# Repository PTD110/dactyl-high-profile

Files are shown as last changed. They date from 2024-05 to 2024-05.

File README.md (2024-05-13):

# Yet another Dactyl Manuform Spinoff (Low Profile)



This repo is a _fork of a_ re-implementation of the [Dactyl Manuform Tight](https://github.com/okke-formsma/dactyl-manuform-tight) in python, with a few of my own changes.

There are some hacks in here to get the border walls and thumb cluster to line up properly at the current tenting angle and key layout.
I didn't build this script with the goal of making it easy to share and extend... so if you're using this repo as a starting point for your own dactyl build, good luck, and beware of some shard edges.

## Generating OpenSCAD Models

This script is tested against Python 3.8.0

Intall dependencies with `pip install -r requirements.txt`

Run a one-off scad model build with `make run`

Watch and rebuild scad models with `make watch` (useful for development)

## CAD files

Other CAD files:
things/left.scad
things/left_bottom_plate.scad
things/right.scad
things/right_bottom_plate.scad

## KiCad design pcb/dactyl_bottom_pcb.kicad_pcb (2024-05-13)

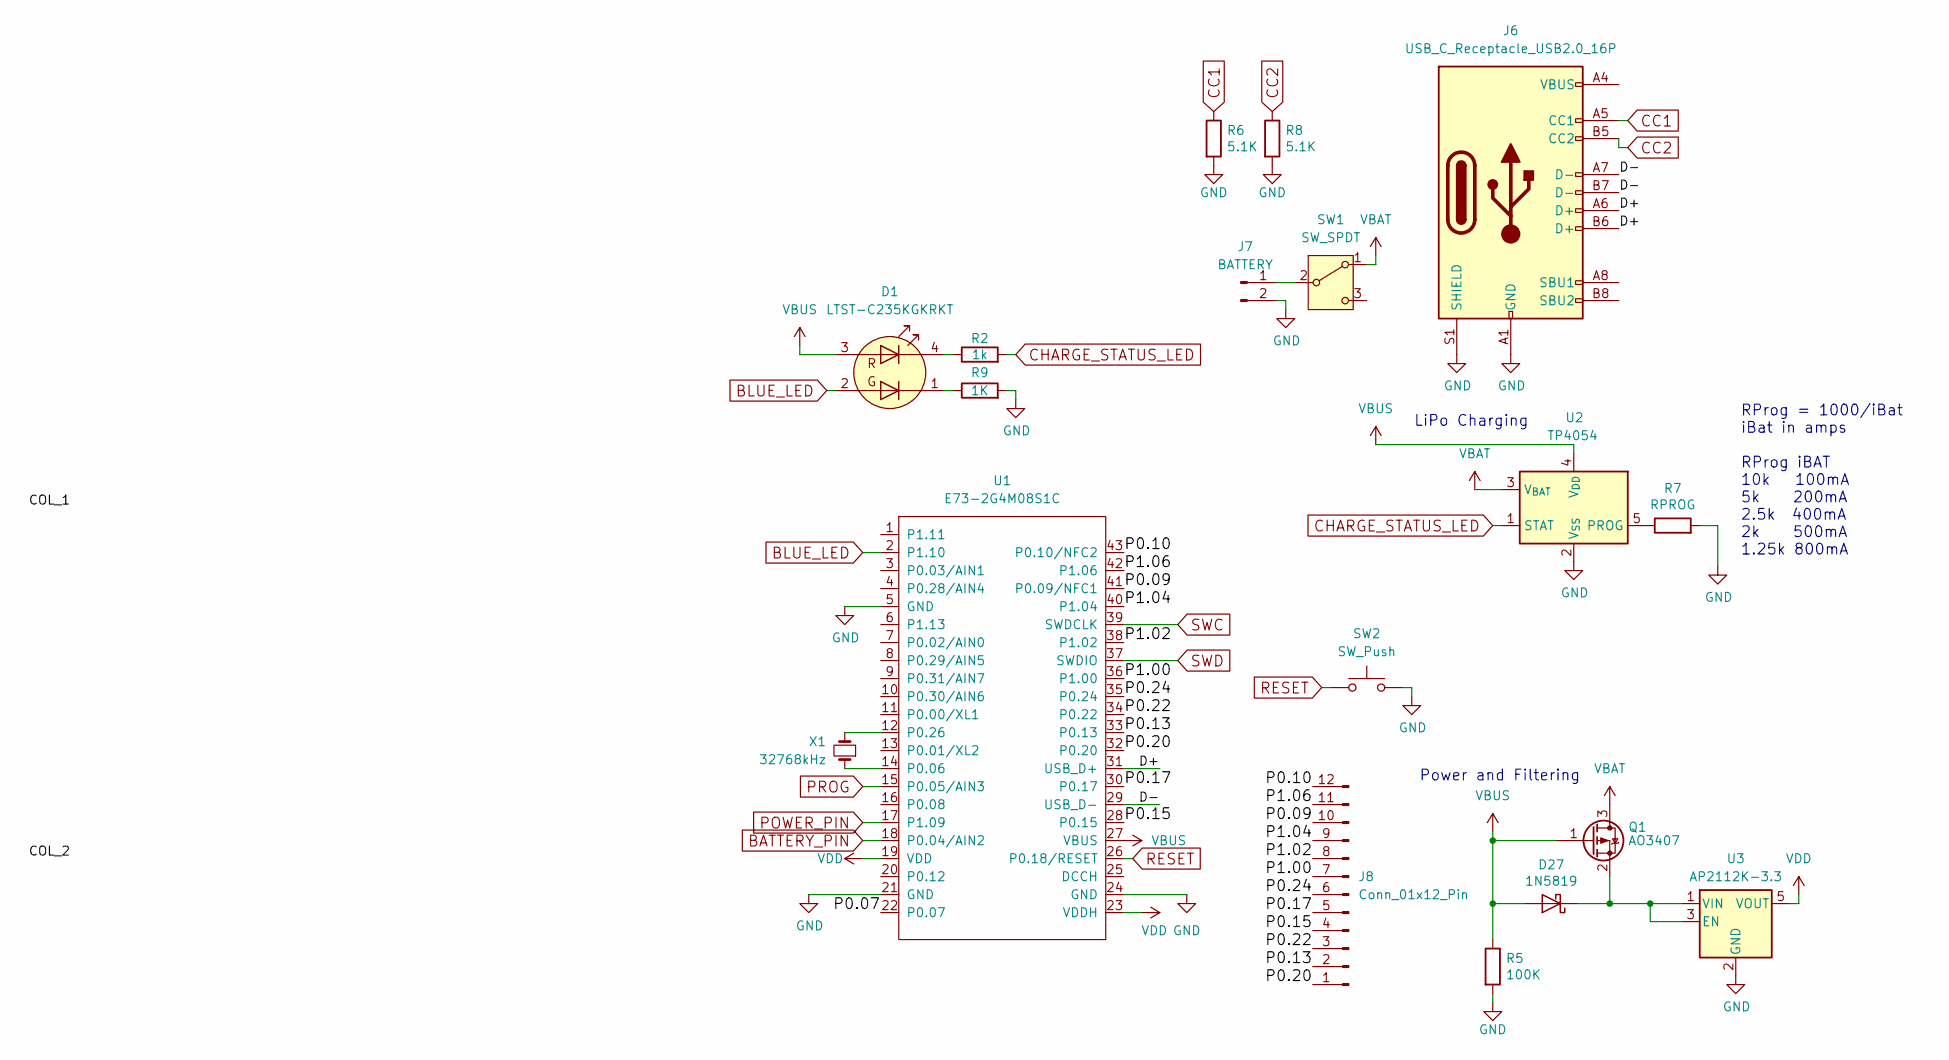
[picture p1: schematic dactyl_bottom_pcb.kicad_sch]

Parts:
D1: LTST-C235KGKRKT; LED_LiteOn_LTST-C235KGKRKT
D27: 1N5819; D_SOD-323F
J6: USB_C_Receptacle_USB2.0_16P; USB_C_Receptacle_GCT_USB4105-xx-A_16P_TopMnt_Horizontal
J7: BATTERY; JST_PH_S2B-PH-SM4-TB_1x02-1MP_P2.00mm_Horizontal
J8: Conn_01x12_Pin; JST_SH_SM12B-SRSS-TB_1x12-1MP_P1.00mm_Horizontal
Q1: AO3407; SOT-23
R2: 1k; R_0603_1608Metric_Pad0.98x0.95mm_HandSolder
R5: 100K; R_0603_1608Metric
R6, R8: 5.1K; R_0603_1608Metric
R7: RPROG; R_0603_1608Metric
R9: 1K; R_0603_1608Metric
SW1: SW_SPDT; SW_SP3T_PCM13
SW2: SW_Push; SW_Push_SPST_NO_Alps_SKRK
U1: E73-2G4M08S1C; E73-2G4M08S1C-52840
U2: TP4054; SOT-23-5
U3: AP2112K-3.3; SOT-23-5
X1: 32768kHz

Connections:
/D+: J6.A6 (D+), J6.B6 (D+), U1.31 (USB_D+)
/D-: J6.A7 (D-), J6.B7 (D-), U1.29 (USB_D-)
/P0.07: U1.22 (P0.07)
/P0.09: J8.10, U1.41 (P0.09/NFC1)
/P0.10: J8.12, U1.43 (P0.10/NFC2)
/P0.13: J8.2, U1.33 (P0.13)
/P0.15: J8.4, U1.28 (P0.15)
/P0.17: J8.5, U1.30 (P0.17)
/P0.20: J8.1, U1.32 (P0.20)
/P0.22: J8.3, U1.34 (P0.22)
/P0.24: J8.6, U1.35 (P0.24)
/P1.00: J8.7, U1.36 (P1.00)
/P1.02: J8.8, U1.38 (P1.02)
/P1.04: J8.9, U1.40 (P1.04)
/P1.06: J8.11, U1.42 (P1.06)
BATTERY_PIN: U1.18 (P0.04/AIN2)
BLUE_LED: D1.2 (A2), U1.2 (P1.10)
CC1: J6.A5 (CC1), R6.1
CC2: J6.B5 (CC2), R8.1
CHARGE_STATUS_LED: R2.2, U2.1 (STAT)
GND: J6.A1 (GND), J6.A12 (GND), J6.B1 (GND), J6.B12 (GND), J6.S1 (SHIELD), J7.2, R5.2, R6.2, R7.2, R8.2, R9.2, SW2.2, U1.5 (GND), U1.21 (GND), U1.24 (GND), U2.2 (V_{SS}), U3.2 (GND)
unnamed: D1.4 (K1), R2.1
unnamed: D1.1 (K2), R9.1
unnamed: D27.1 (K), Q1.2 (S), U3.1 (VIN), U3.3 (EN)
unnamed: J6.A4 (VBUS), J6.A9 (VBUS), J6.B4 (VBUS), J6.B9 (VBUS)
unnamed: J7.1, SW1.2 (B)
unnamed: U1.14 (P0.06), X1.1
unnamed: U1.12 (P0.26), X1.2
unnamed: R7.1, U2.5 (PROG)
POWER_PIN: U1.17 (P1.09)
PROG: U1.15 (P0.05/AIN3)
RESET: SW2.1, U1.26 (P0.18/RESET)
SWC: U1.39 (SWDCLK)
SWD: U1.37 (SWDIO)
VBAT: Q1.3 (D), SW1.1 (A), U2.3 (V_{BAT})
VBUS: D1.3 (A1), D27.2 (A), Q1.1 (G), R5.1, U1.27 (VBUS), U2.4 (V_{DD})
VDD: U1.19 (VDD), U1.23 (VDDH), U3.5 (VOUT)

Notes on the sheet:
Power and Filtering
LiPo Charging
RProg = 1000/iBat iBat in amps RProg iBAT 10k 100mA 5k 200mA 2.5k 400mA 2k 500mA 1.25k 800mA

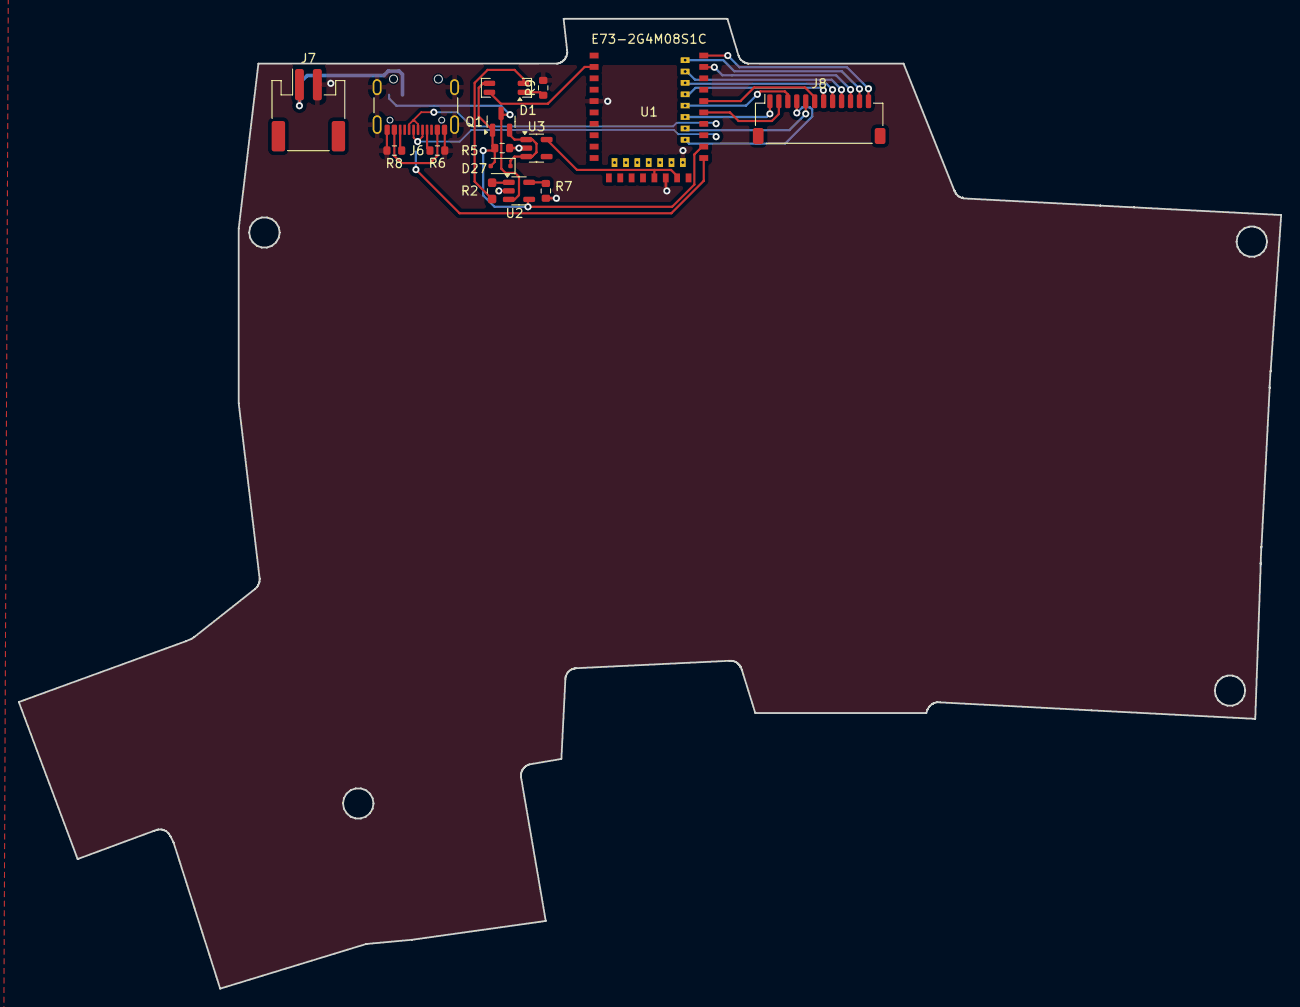
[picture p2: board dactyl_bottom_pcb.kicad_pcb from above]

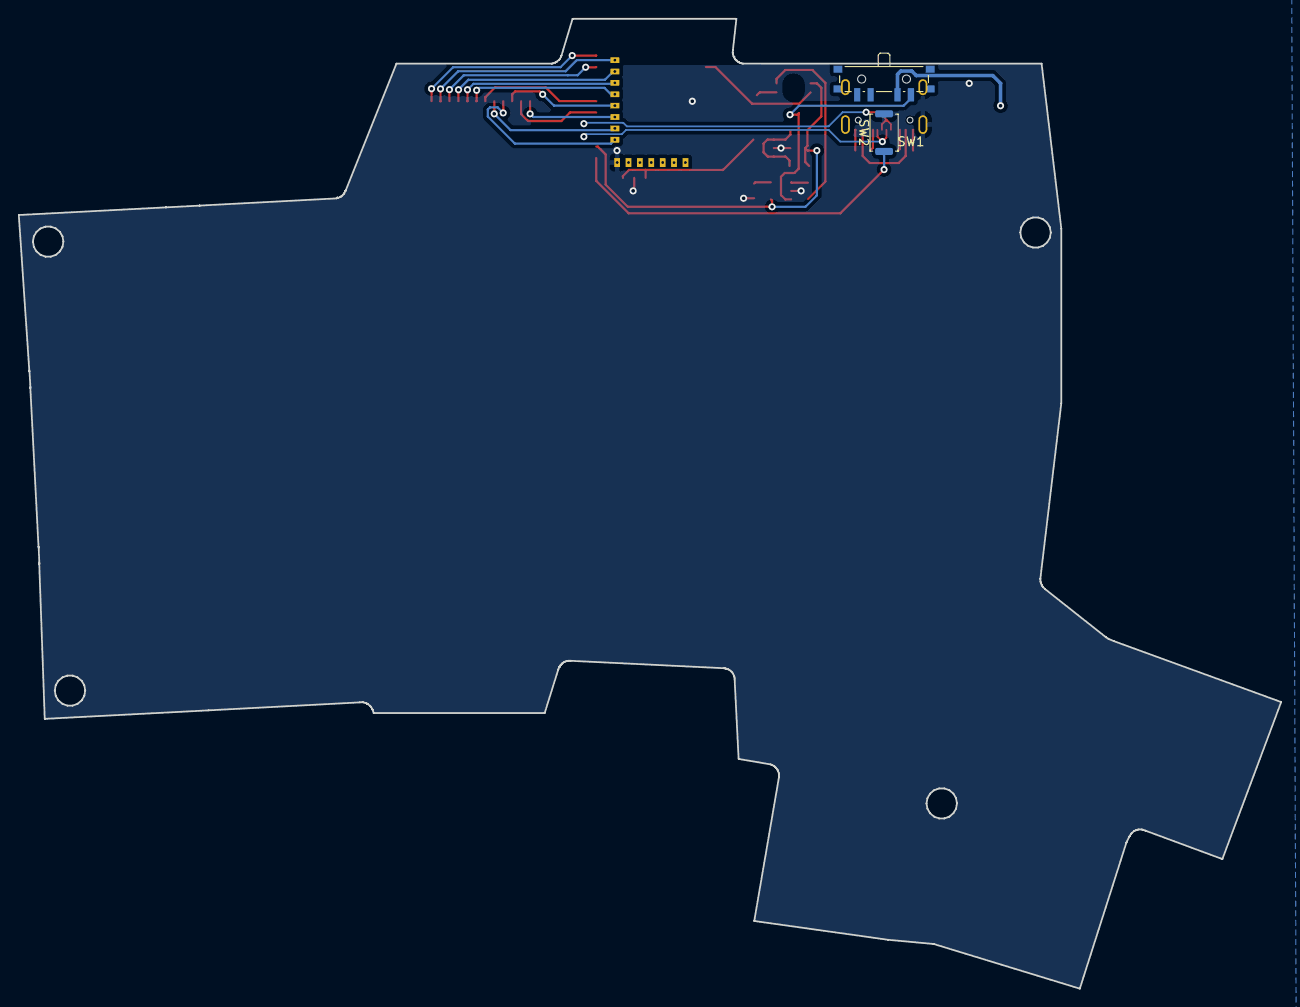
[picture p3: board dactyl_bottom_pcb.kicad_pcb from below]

Board: 2 copper layers, 140.9 x 108.2 mm, 17 parts (2 on the bottom side), 29 nets.

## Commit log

2024-05-13 tweaks to mounting holes
    [left.scad, left.stl, left_bottom_plate.scad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]
2024-05-13 add PCB files
    [dactyl_bottom_pcb.kicad_pcb, dactyl_bottom_pcb.kicad_sch, dactyl_bottom_pcb.sch]
